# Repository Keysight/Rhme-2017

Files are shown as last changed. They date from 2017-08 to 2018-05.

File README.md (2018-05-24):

# Rhme-2017-2018
Riscure Hack Me embedded hardware CTF 2017-2018

# Pre-qualifications

## Write-ups

* [ResultsMayVary](https://github.com/ResultsMayVary/ctf/tree/master/RHME3)
* [Grazfather](https://grazfather.github.io/ctf/re/crypto/2017/09/03/RHME3-Quals-Whitebox.html)
* [Govanify](https://govanify.com/post/rhme3-quals-ctf/)

# Main Event

## Write-ups
Here's a list of writeups on RHme3. Please add any that are missing

* [S0S1 (2nd place)](https://s0s1-team.github.io/ctf)
* [S0S1 (2nd place)](https://github.com/s0s1-team/ctf/tree/master/rhme3)
* [Cloakware (3rd place)](https://github.com/cloakware-ctf/rhme3-writeups)
* [GabrielGO (5th place)](https://github.com/gabrielgo-ctf/write-ups/tree/master/RHme3)
* [p4 (6th place)](https://github.com/p4-team/ctf/tree/master/2018-04-30-rhme3)
* [TomHaramori (24th place)](https://github.com/haramori/rhme3)
* [Kleinspider (41st place)](https://kleinspider.github.io/writeups/rhme3/overview)

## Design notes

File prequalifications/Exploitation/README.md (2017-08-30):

# Exploitation

This binary is (actually was, during the prequalification stage, but not anymore) running on pwn.rhme.riscure.com.
Analyze it and find a way to compromise the server. You’ll find the flag in the filesystem.

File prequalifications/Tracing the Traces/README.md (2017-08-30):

# Tracing the Traces

These traces (.trs and .mat format) were captured from a hardware device performing a certain cryptographic calculation.
The trace files contain input/output data as well as the corresponding power measurements for (part of) the
cryptographic operation. Can you get the key?

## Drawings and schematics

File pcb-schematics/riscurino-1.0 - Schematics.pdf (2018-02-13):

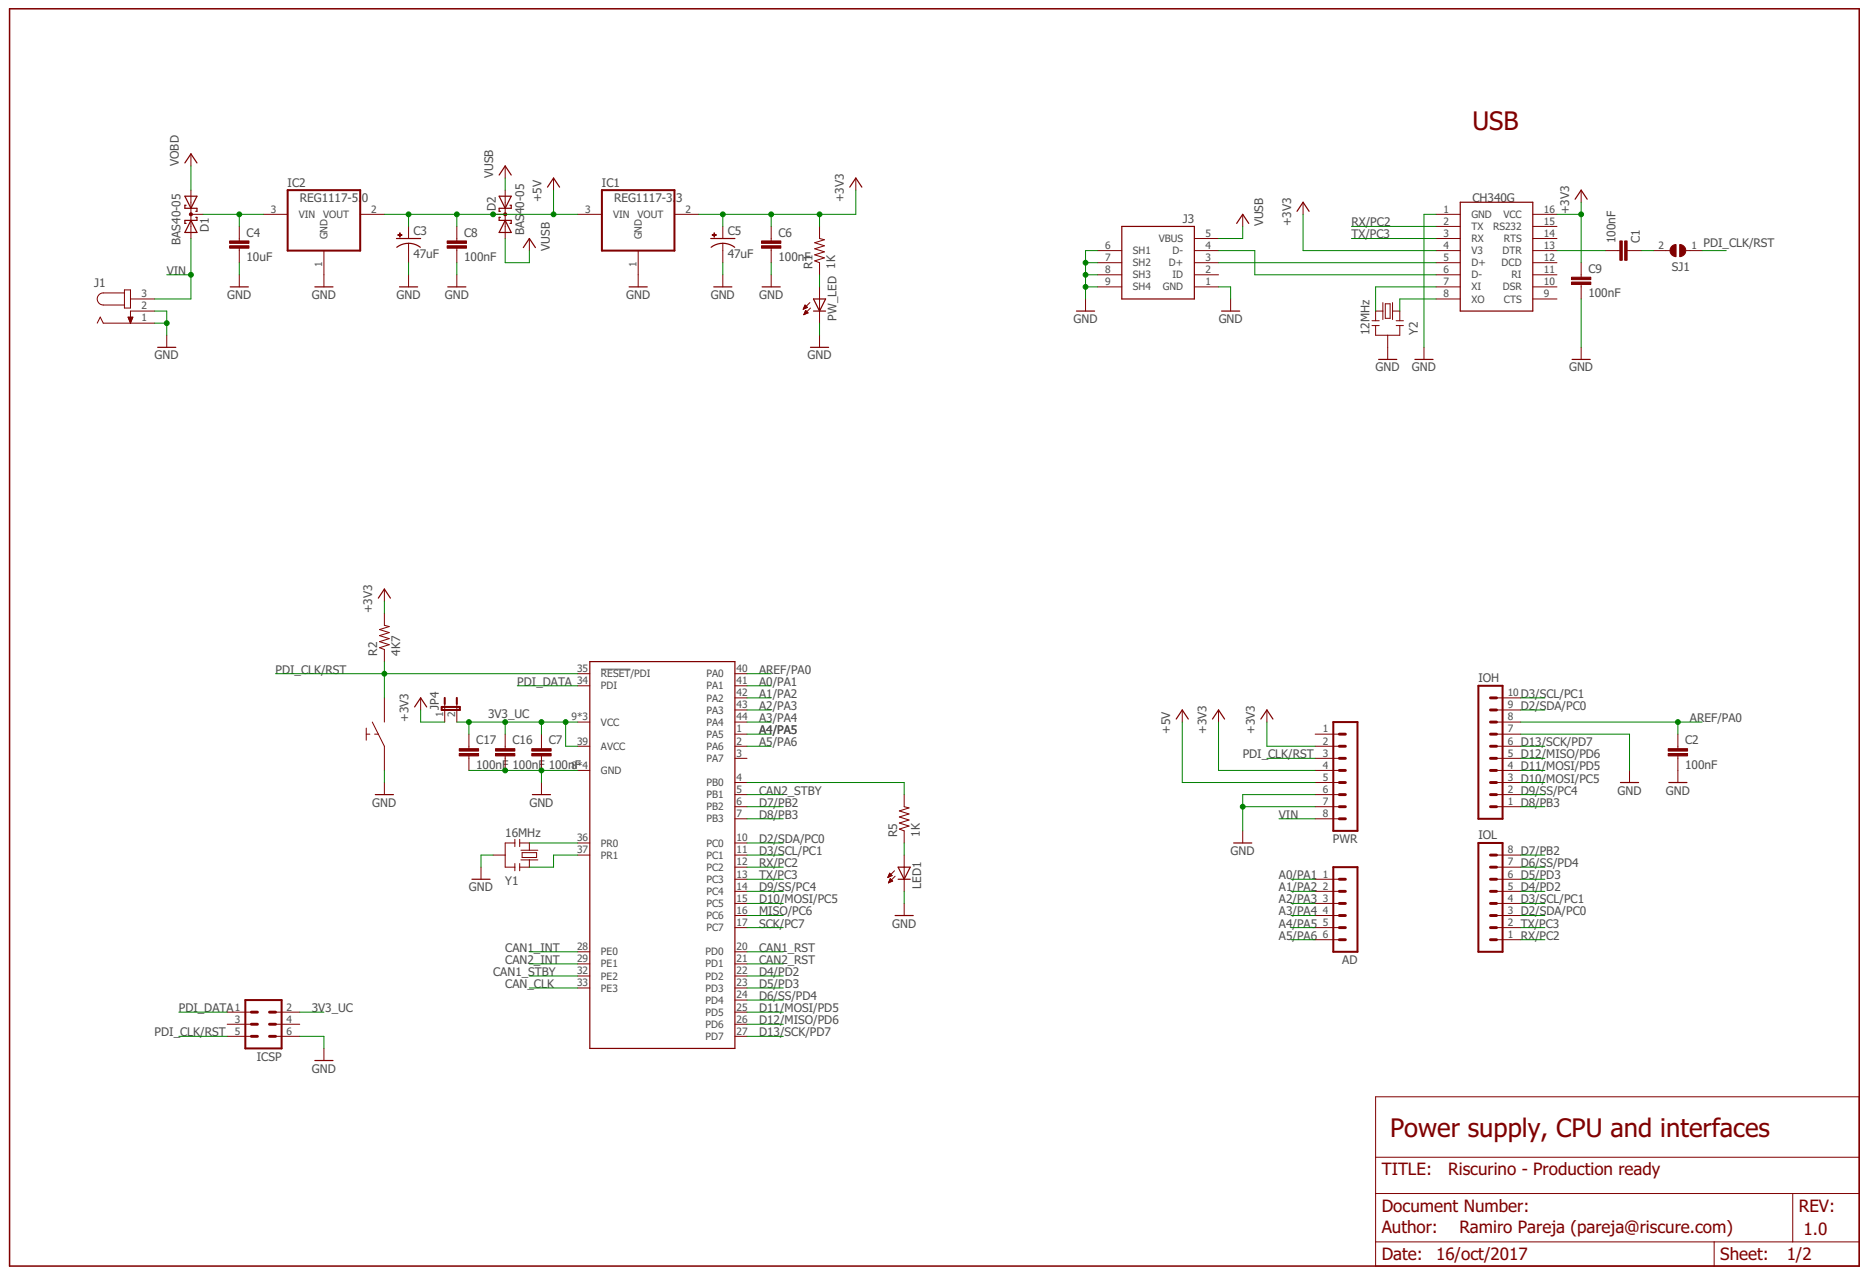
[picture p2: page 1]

Power supply, CPU and interfaces

Document Number: Author: Ramiro Pareja (pareja@riscure.com) | REV: 1.0

Date: 16/oct/2017 | Sheet: 1/2

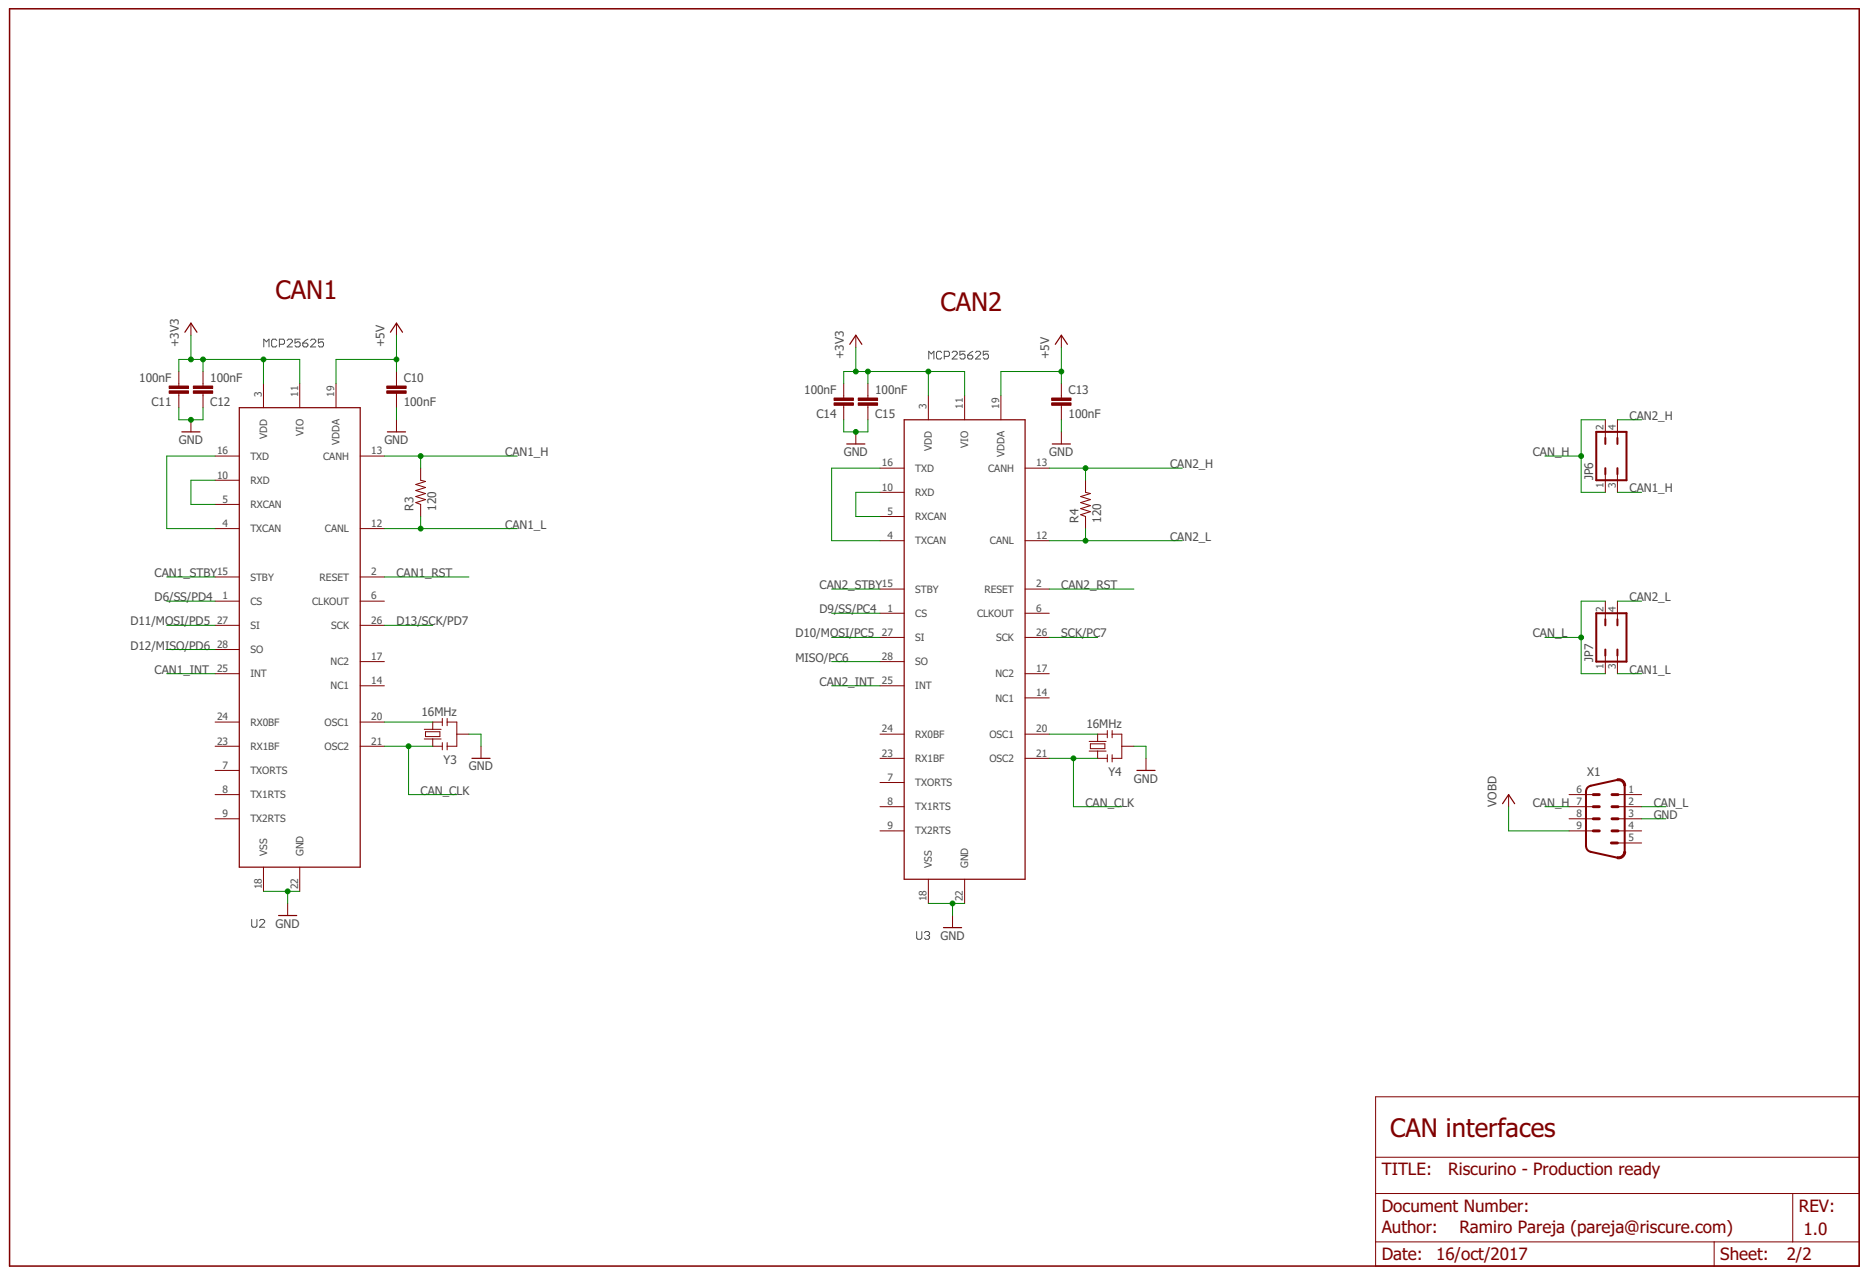
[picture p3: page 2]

120 +3V3 100nF GND 100nF 100nF GND GND 16MHz GND 120 +3V3 100nF GND 100nF 100nF GND GND 16MHz GND VOBD +5V +5V VIO 11 NC1 14 CANL 12 CANH 13 STBY 15 TX1RTS 8 TX2RTS 9 OSC2 21 OSC1 20 GND 22 RX1BF 23 RX0BF 24 INT 25 SCK 26 SI 27 SO 28 CS 1 RESET 2 VDD 3 TXCAN 4 RXCAN 5 CLKOUT 6 TXORTS 7 TXD 16 NC2 17 VSS 18 VDDA 19 RXD 10 R3 C10 C11 C12 Y3 VIO 11 NC1 14 CANL 12 CANH 13 STBY 15 TX1RTS 8 TX2RTS 9 OSC2 21 OSC1 20 GND 22 RX1BF 23 RX0BF 24 INT 25 SCK 26 SI 27 SO 28 CS 1 RESET 2 VDD 3 TXCAN 4 RXCAN 5 CLKOUT 6 TXORTS 7 TXD 16 NC2 17 VSS 18 VDDA 19 RXD 10 R4 C13 C14 C15 Y4 X1 6 1 7 2 8 3 9 45 JP6 1 2 3 4 JP7 1 2 3 4 GND CAN_CLK CAN_CLK CAN2_L CAN2_L CAN1_H CAN1_H D6/SS/PD4 D10/MOSI/PC5 D11/MOSI/PD5 D12/MISO/PD6 D13/SCK/PD7 CAN1_INT CAN2_INT CAN1_STBY CAN1_RST CAN2_RST CAN1_L CAN1_L CAN2_H CAN2_H D9/SS/PC4 MISO/PC6 SCK/PC7 CAN_H CAN_H CAN_L CAN_L CAN2_STBY CAN1 CAN2 Riscurino - Production ready 1.0 16/oct/2017 Author: Ramiro Pareja (pareja@riscure.com) CAN interfaces Date: Sheet: REV: TITLE: Document Number: 2/2

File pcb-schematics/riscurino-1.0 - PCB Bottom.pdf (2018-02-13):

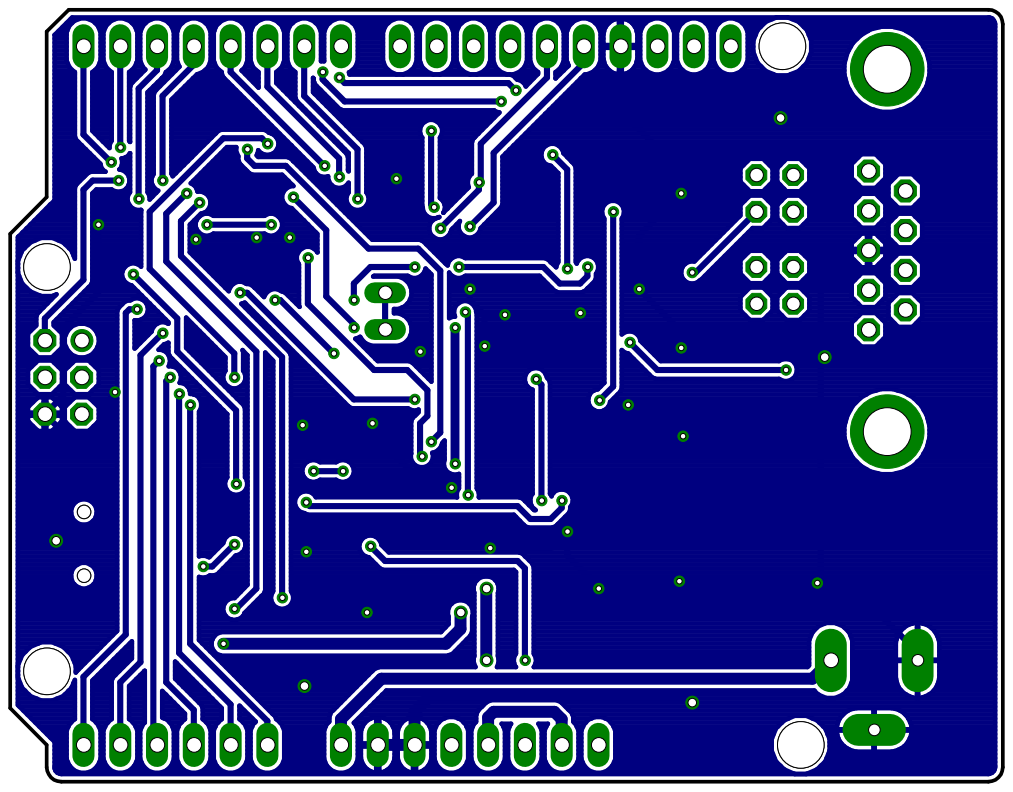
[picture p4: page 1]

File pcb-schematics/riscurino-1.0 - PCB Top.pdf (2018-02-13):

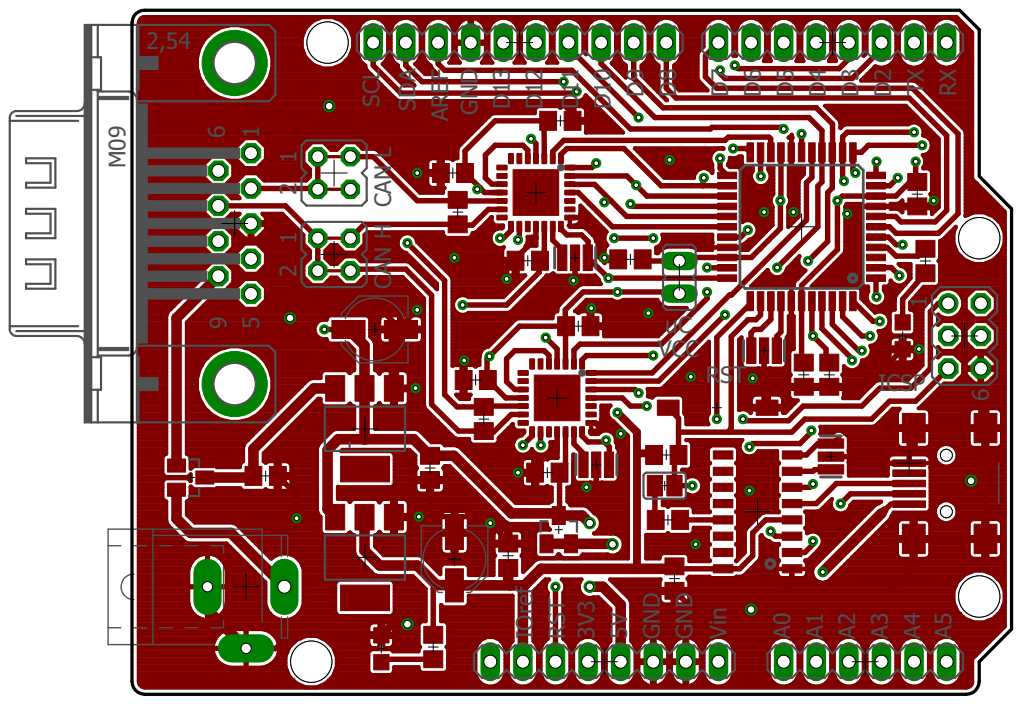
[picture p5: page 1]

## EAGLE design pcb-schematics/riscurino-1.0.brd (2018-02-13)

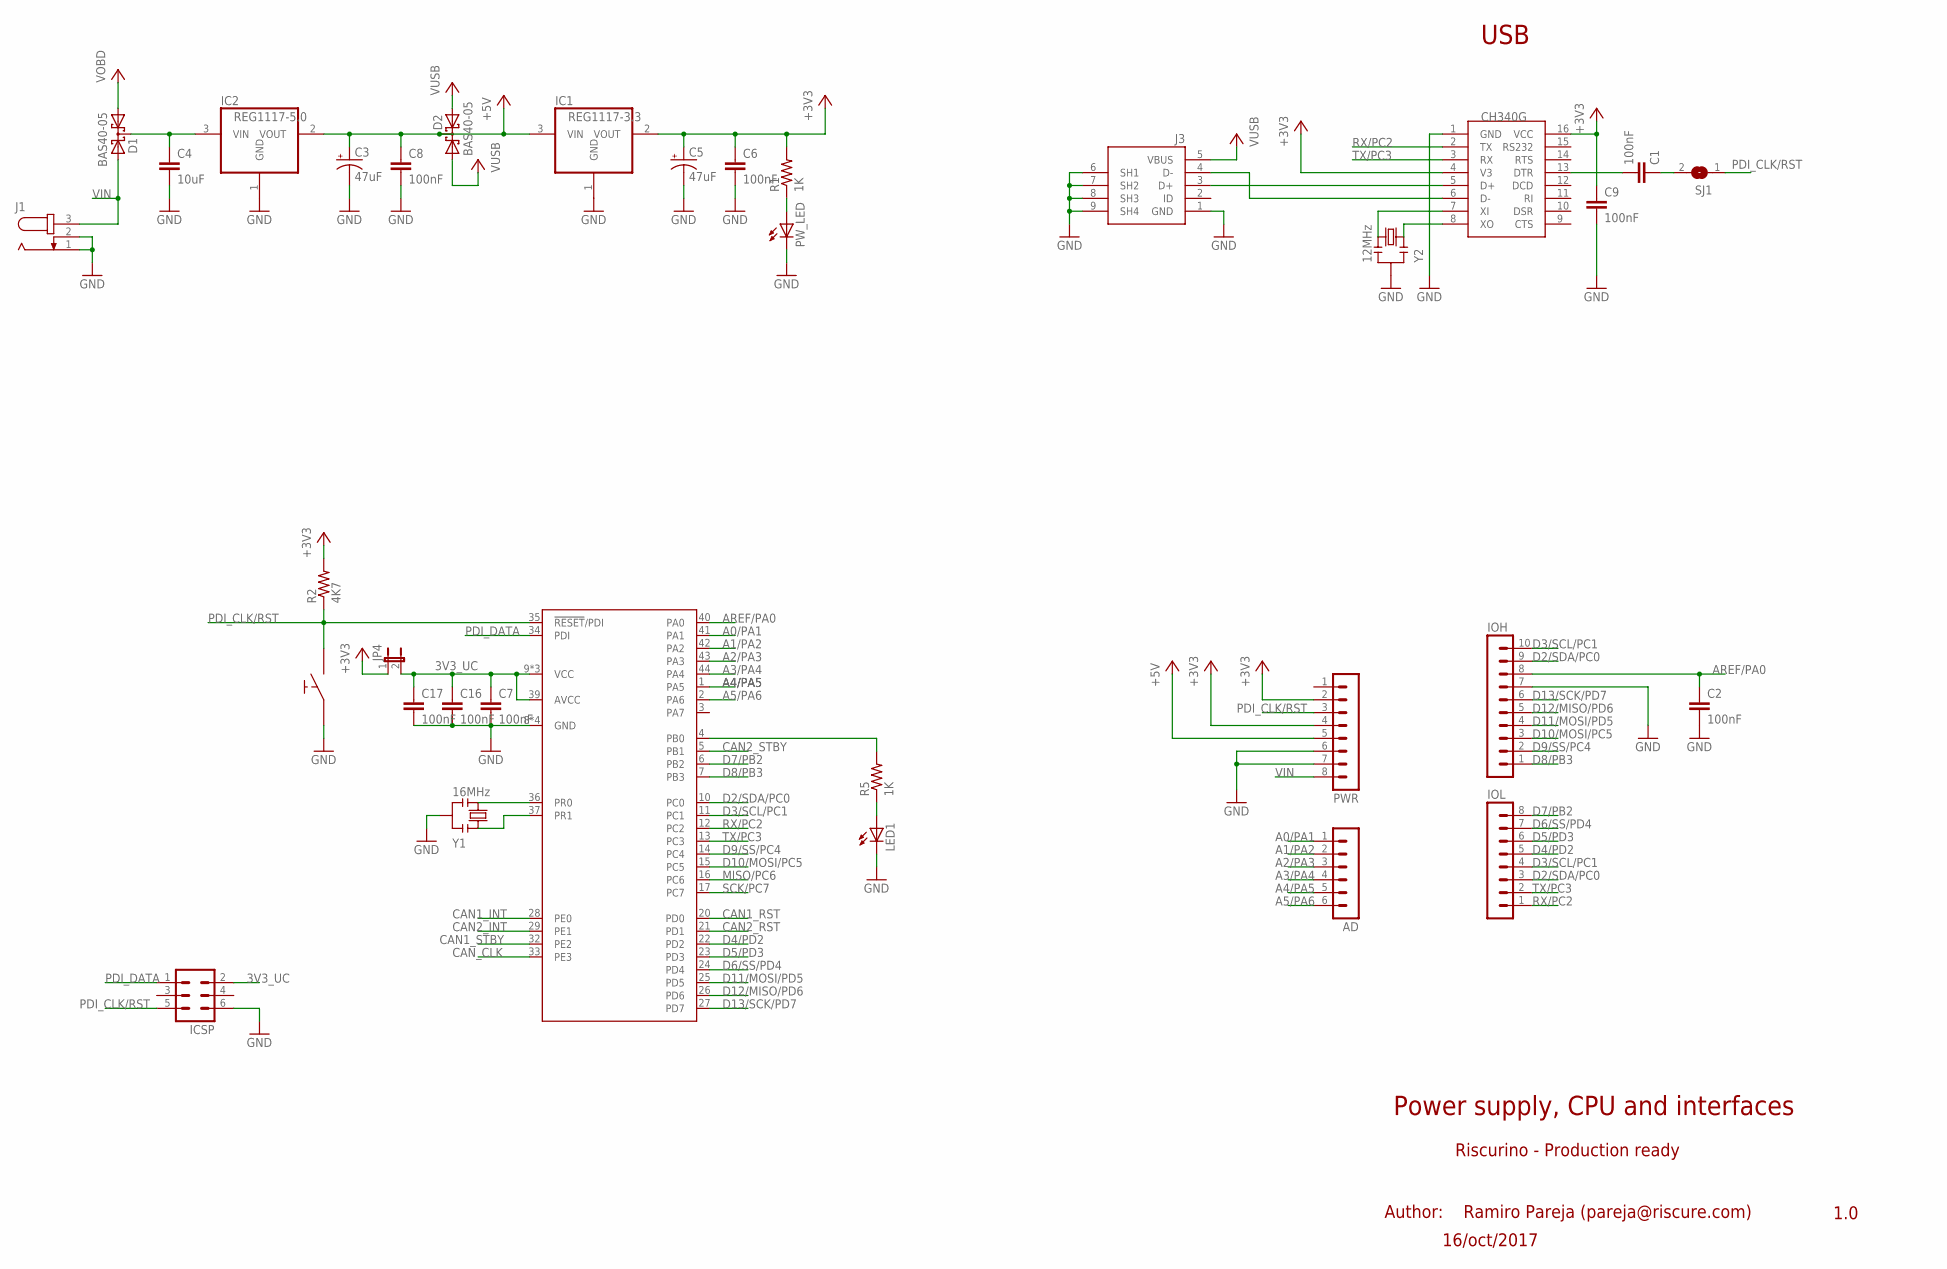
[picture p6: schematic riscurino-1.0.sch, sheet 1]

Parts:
AD: MA06-1
C1, C2, C6, C7, C8, C9, C16, C17: 100nF; C0805
C3, C5: 47uF; PANASONIC_C
C4: 10uF; C0805
D1, D2: BAS40-05; SOT23
IC1: REG1117-3.3; SOT223
IC2: REG1117-5.0; SOT223
ICSP: MA03-2
IOH: MA10-1
IOL: MA08-1
J1: JACK-PLUG0; SPC4077
J3: 0219_14850; USB-MINI-B_2
JP4: JP1E; JP1
LED1: LEDCHIPLED_0805; CHIPLED_0805
PWR: MA08-1
PW_LED: LEDCHIPLED_0805; CHIPLED_0805
R1, R5: 1K; R0805
R2: 4K7; R0805
SJ1: SJ
U1: ATXMEGA128A4U-AU; TQFP-44A-44
U4: CH340G; SOIC16
U$1: SWITCH_3X6_BIG
Y1: 16MHz; RESONATOR
Y2: 12MHz; RESONATOR

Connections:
3V3_UC: C7.1, C16.1, C17.1, ICSP.2, JP4.2, U1.9 (VCC), U1.19 (VCC), U1.31 (VCC), U1.39 (AVCC)
+3V3: C5.+, C6.1, C9.1, IC1.2 (VOUT), JP4.1, PWR.2, PWR.4, R1.2, R2.2, U4.4 (V3), U4.16 (VCC); also elsewhere on the board
+5V: C3.+, C8.1, D2.3 (C), IC1.3 (VIN), IC2.2 (VOUT), PWR.5; also elsewhere on the board
A0/PA1: AD.1, U1.41 (PA1)
A1/PA2: AD.2, U1.42 (PA2)
A2/PA3: AD.3, U1.43 (PA3)
A3/PA4: AD.4, U1.44 (PA4)
A4/PA5: AD.5, U1.1 (PA5)
A5/PA6: AD.6, U1.2 (PA6)
AREF/PA0: C2.1, IOH.8, U1.40 (PA0)
CAN1_INT: U1.28 (PE0); also elsewhere on the board
CAN1_RST: U1.20 (PD0); also elsewhere on the board
CAN1_STBY: U1.32 (PE2); also elsewhere on the board
CAN2_INT: U1.29 (PE1); also elsewhere on the board
CAN2_RST: U1.21 (PD1); also elsewhere on the board
CAN2_STBY: U1.5 (PB1); also elsewhere on the board
CAN_CLK: U1.33 (PE3); also elsewhere on the board
D2/SDA/PC0: IOH.9, IOL.3, U1.10 (PC0)
D3/SCL/PC1: IOH.10, IOL.4, U1.11 (PC1)
D4/PD2: IOL.5, U1.22 (PD2)
D5/PD3: IOL.6, U1.23 (PD3)
D6/SS/PD4: IOL.7, U1.24 (PD4); also elsewhere on the board
D7/PB2: IOL.8, U1.6 (PB2)
D8/PB3: IOH.1, U1.7 (PB3)
D9/SS/PC4: IOH.2, U1.14 (PC4); also elsewhere on the board
D10/MOSI/PC5: IOH.3, U1.15 (PC5); also elsewhere on the board
D11/MOSI/PD5: IOH.4, U1.25 (PD5); also elsewhere on the board
D12/MISO/PD6: IOH.5, U1.26 (PD6); also elsewhere on the board
D13/SCK/PD7: IOH.6, U1.27 (PD7); also elsewhere on the board
GND: C2.2, C3.-, C4.2, C5.-, C6.2, C7.2, C8.2, C9.2, C16.2, C17.2, IC1.1 (GND), IC2.1 (GND), ICSP.6, IOH.7, J1.1, J1.2, J3.1 (GND), J3.6 (SH1), J3.7 (SH2), J3.8 (SH3), J3.9 (SH4), LED1.C, PWR.6, PWR.7, PW_LED.C, U1.8 (GND), U1.18 (GND), U1.30 (GND), U1.38 (GND), U4.1 (GND), U$1.P$1, Y1.2, Y2.2; also elsewhere on the board
MISO/PC6: U1.16 (PC6); also elsewhere on the board
unnamed: U1.36 (PR0), Y1.3
unnamed: U1.37 (PR1), Y1.1
unnamed: C1.2, U4.13 (DTR)
unnamed: C4.1, D1.3 (C), IC2.3 (VIN)
unnamed: J3.3 (D+), U4.5 (D+)
unnamed: PW_LED.A, R1.1
unnamed: J3.4 (D-), U4.6 (D-)
unnamed: LED1.A, R5.1
unnamed: C1.1, SJ1.2
unnamed: U4.8 (XO), Y2.1
unnamed: U4.7 (XI), Y2.3
unnamed: R5.2, U1.4 (PB0)
PDI_CLK/RST: ICSP.5, PWR.3, R2.1, SJ1.1, U1.35 (!RESET!/PDI), U$1.P$2
PDI_DATA: ICSP.1, U1.34 (PDI)
RX/PC2: IOL.1, U1.12 (PC2), U4.2 (TX)
SCK/PC7: U1.17 (PC7); also elsewhere on the board
TX/PC3: IOL.2, U1.13 (PC3), U4.3 (RX)
VIN: D1.2 (A2), J1.3, PWR.8
VOBD: D1.1 (A1); also elsewhere on the board
VUSB: D2.1 (A1), D2.2 (A2), J3.5 (VBUS)

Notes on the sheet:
USB
Riscurino - Production ready
1.0
16/oct/2017
Author: Ramiro Pareja (pareja@riscure.com)
Power supply, CPU and interfaces

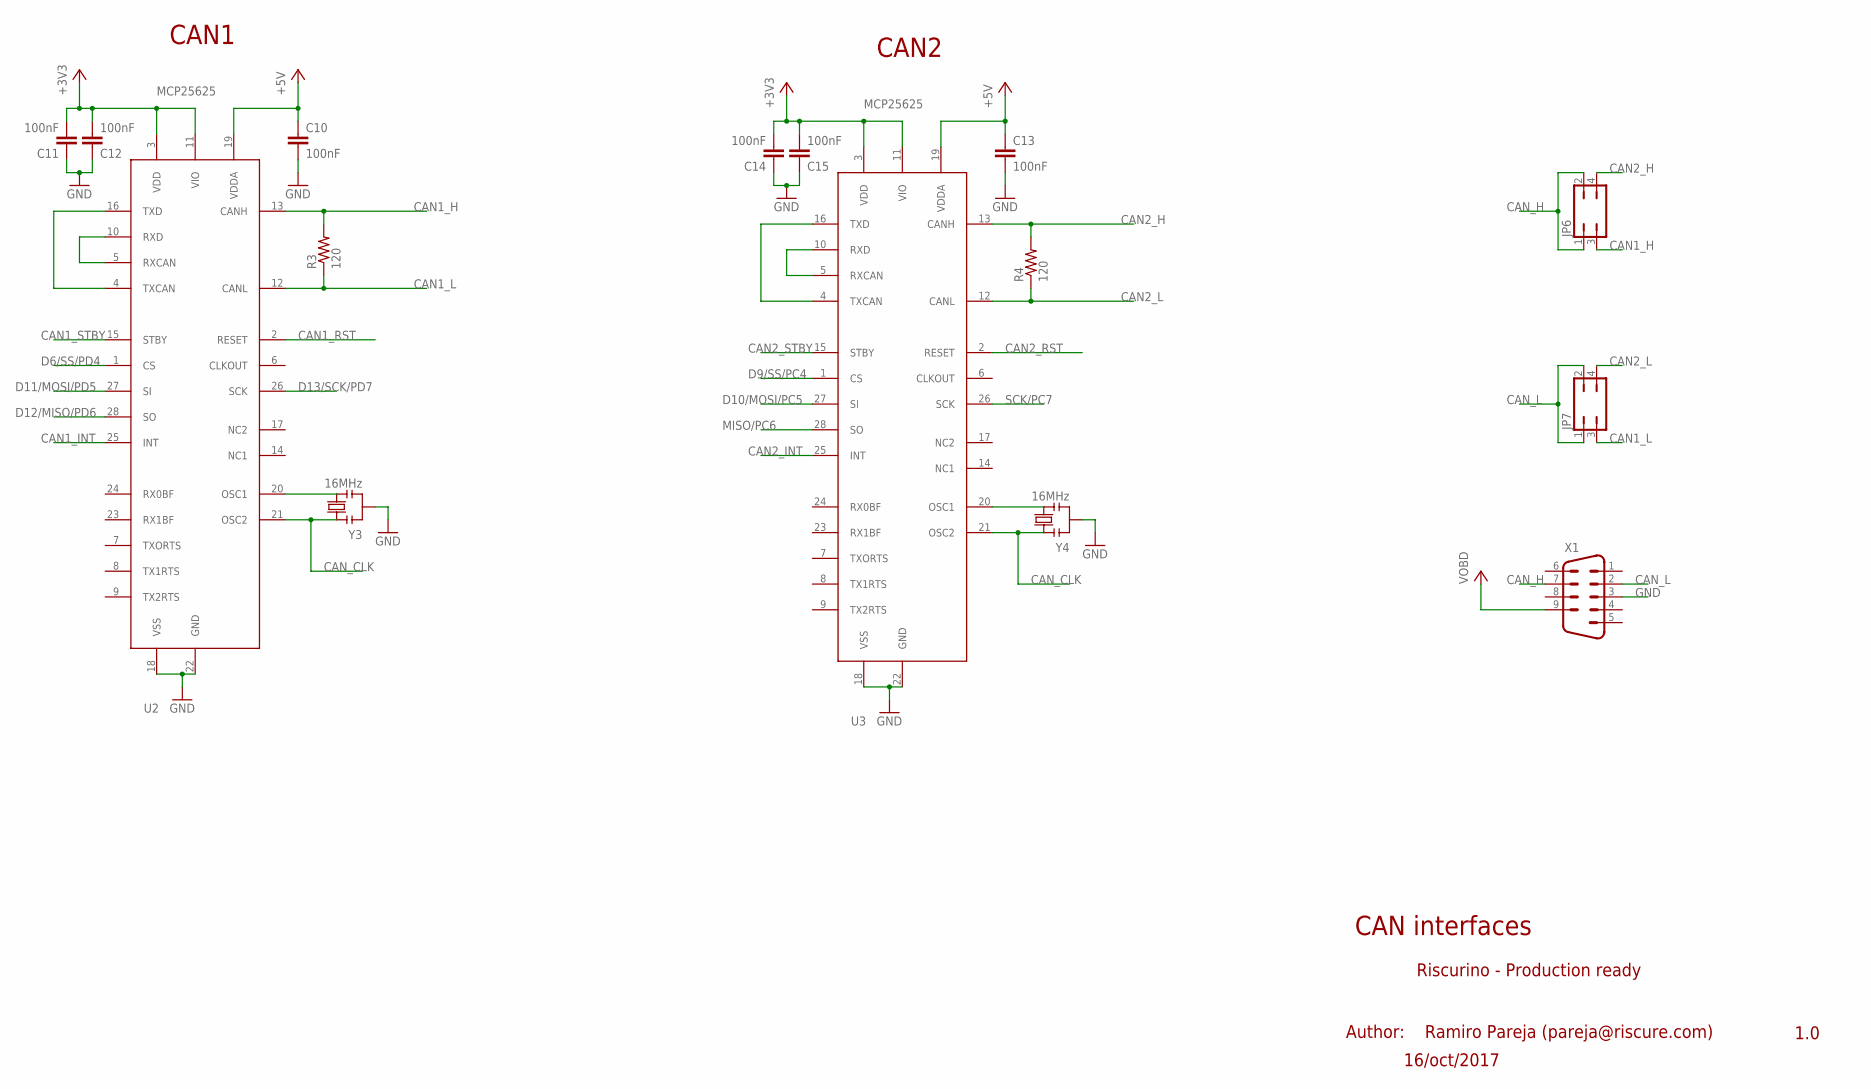
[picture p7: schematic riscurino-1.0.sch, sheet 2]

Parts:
C10, C11, C12, C13, C14, C15: 100nF; C0805
JP6, JP7: JP2Q
R3, R4: 120; R0805
U2, U3: MCP25625; QFN28
X1: M09HP
Y3, Y4: 16MHz; RESONATOR

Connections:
+3V3: C11.2, C12.2, C14.2, C15.2, U2.3 (VDD), U2.11 (VIO), U3.3 (VDD), U3.11 (VIO); also elsewhere on the board
+5V: C10.1, C13.1, U2.19 (VDDA), U3.19 (VDDA); also elsewhere on the board
CAN1_H: JP6.3, R3.2, U2.13 (CANH)
CAN1_INT: U2.25 (INT); also elsewhere on the board
CAN1_L: JP7.3, R3.1, U2.12 (CANL)
CAN1_RST: U2.2 (RESET); also elsewhere on the board
CAN1_STBY: U2.15 (STBY); also elsewhere on the board
CAN2_H: JP6.4, R4.2, U3.13 (CANH)
CAN2_INT: U3.25 (INT); also elsewhere on the board
CAN2_L: JP7.4, R4.1, U3.12 (CANL)
CAN2_RST: U3.2 (RESET); also elsewhere on the board
CAN2_STBY: U3.15 (STBY); also elsewhere on the board
CAN_CLK: U2.21 (OSC2), U3.21 (OSC2), Y3.1, Y4.1; also elsewhere on the board
CAN_H: JP6.1, JP6.2, X1.7
CAN_L: JP7.1, JP7.2, X1.2
D6/SS/PD4: U2.1 (CS); also elsewhere on the board
D9/SS/PC4: U3.1 (CS); also elsewhere on the board
D10/MOSI/PC5: U3.27 (SI); also elsewhere on the board
D11/MOSI/PD5: U2.27 (SI); also elsewhere on the board
D12/MISO/PD6: U2.28 (SO); also elsewhere on the board
D13/SCK/PD7: U2.26 (SCK); also elsewhere on the board
GND: C10.2, C11.1, C12.1, C13.2, C14.1, C15.1, U2.18 (VSS), U2.22 (GND), U3.18 (VSS), U3.22 (GND), X1.3, Y3.2, Y4.2; also elsewhere on the board
MISO/PC6: U3.28 (SO); also elsewhere on the board
unnamed: U3.4 (TXCAN), U3.16 (TXD)
unnamed: U2.4 (TXCAN), U2.16 (TXD)
unnamed: U2.5 (RXCAN), U2.10 (RXD)
unnamed: U3.5 (RXCAN), U3.10 (RXD)
unnamed: U2.20 (OSC1), Y3.3
unnamed: U3.20 (OSC1), Y4.3
SCK/PC7: U3.26 (SCK); also elsewhere on the board
VOBD: X1.9; also elsewhere on the board

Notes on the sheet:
CAN1
CAN2
Riscurino - Production ready
1.0
16/oct/2017
Author: Ramiro Pareja (pareja@riscure.com)
CAN interfaces

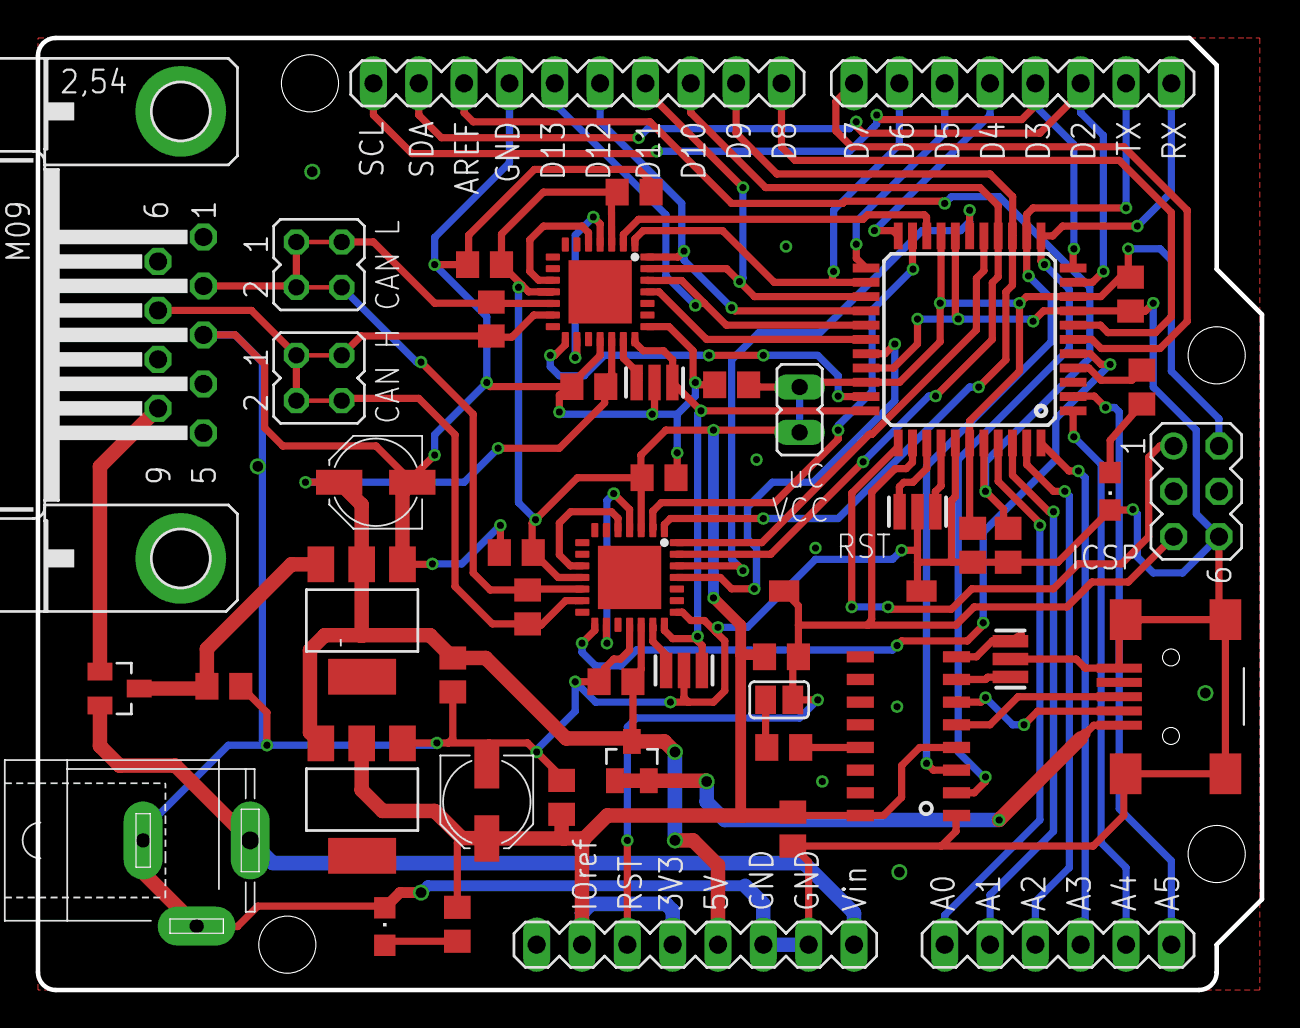
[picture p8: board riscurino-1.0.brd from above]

Board: 2 copper layers, 68.6 x 53.3 mm, 49 parts (0 on the bottom side), 63 nets.

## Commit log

2018-01-22 added the pcb schematics
    [riscurino.brd, riscurino.sch]
2018-02-13 Correct schematics and PCB uploaded.
    [riscurino-1.0.brd, riscurino-1.0.sch, riscurino.brd]
